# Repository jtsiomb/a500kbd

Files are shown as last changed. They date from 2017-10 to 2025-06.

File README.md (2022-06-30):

Amiga 500 PS/2 keyboard controller
==================================

About
-----
This project is a PS/2 keyboard controller for the Amiga 500. It makes it
possible to connect and use an external PS/2 keyboard with the Amiga.

It's based on an AVR atmega168 microcontroller, which reads the PS/2 keyboard
and translates scancodes to the keyboard signals expected by the Amiga.

See pictures of the PS/2 controller in my Amiga: https://imgur.com/a/rhXS8

It has been reported that this works with the A600 too, by soldering directly
on the keyboard clock and data lines. I guess it might work with the A1200 as
well, so if anyone tries it please let me know.

Directory structure:

  * `hw` - hardware: kicad files and pdf schematics.
  * `fw` - firmware for the AVR microcontroller.

Project website: http://nuclear.mutantstargoat.com/hw/amiga/a500kbd

License
-------
Copyright (C) 2017 John Tsiombikas <nuclear@member.fsf.org>

You are free to use, reproduce, modify, redistribute any parts of this project,
provided you make any derivative work you release, freely available under the
same terms.

More specifically the hardware design is released under the Creative Commons
Attribution Share-Alike license (see `LICENSE.hw` for details), and the
software/firmware is released under the GNU General Public License v3, or later
(see `LICENSE.fw` for details).

Instructions
------------
Just construct the hardware, burn the firmware, drill appropriate holes, and
connect everything together. The board is designed to sit on top of the keyboard
connector pins on the Amiga motherboard, and provides a new set of pins for the
internal keyboard to be connected on the board. Two cables need to be connected
from the board to some hole on the Amiga case: one goes to the PS/2 connector,
and the other to the DPDT switch which selects between internal and external
keyboard (see: https://i.imgur.com/ovFDP2b.jpg).

The default key mapping (can only be changed by modifying the source code at the
moment), is as follows:

  * Caps lock key is mapped to control.
  * Left control key is mapped to left amiga key.
  * Right control key is mapped to right amiga key.
  * Scroll lock is mapped to caps lock.
  * F12 is mapped to "Help".

Also the scroll lock light on the external keyboard, mirrors the drive activity
LED on the amiga.

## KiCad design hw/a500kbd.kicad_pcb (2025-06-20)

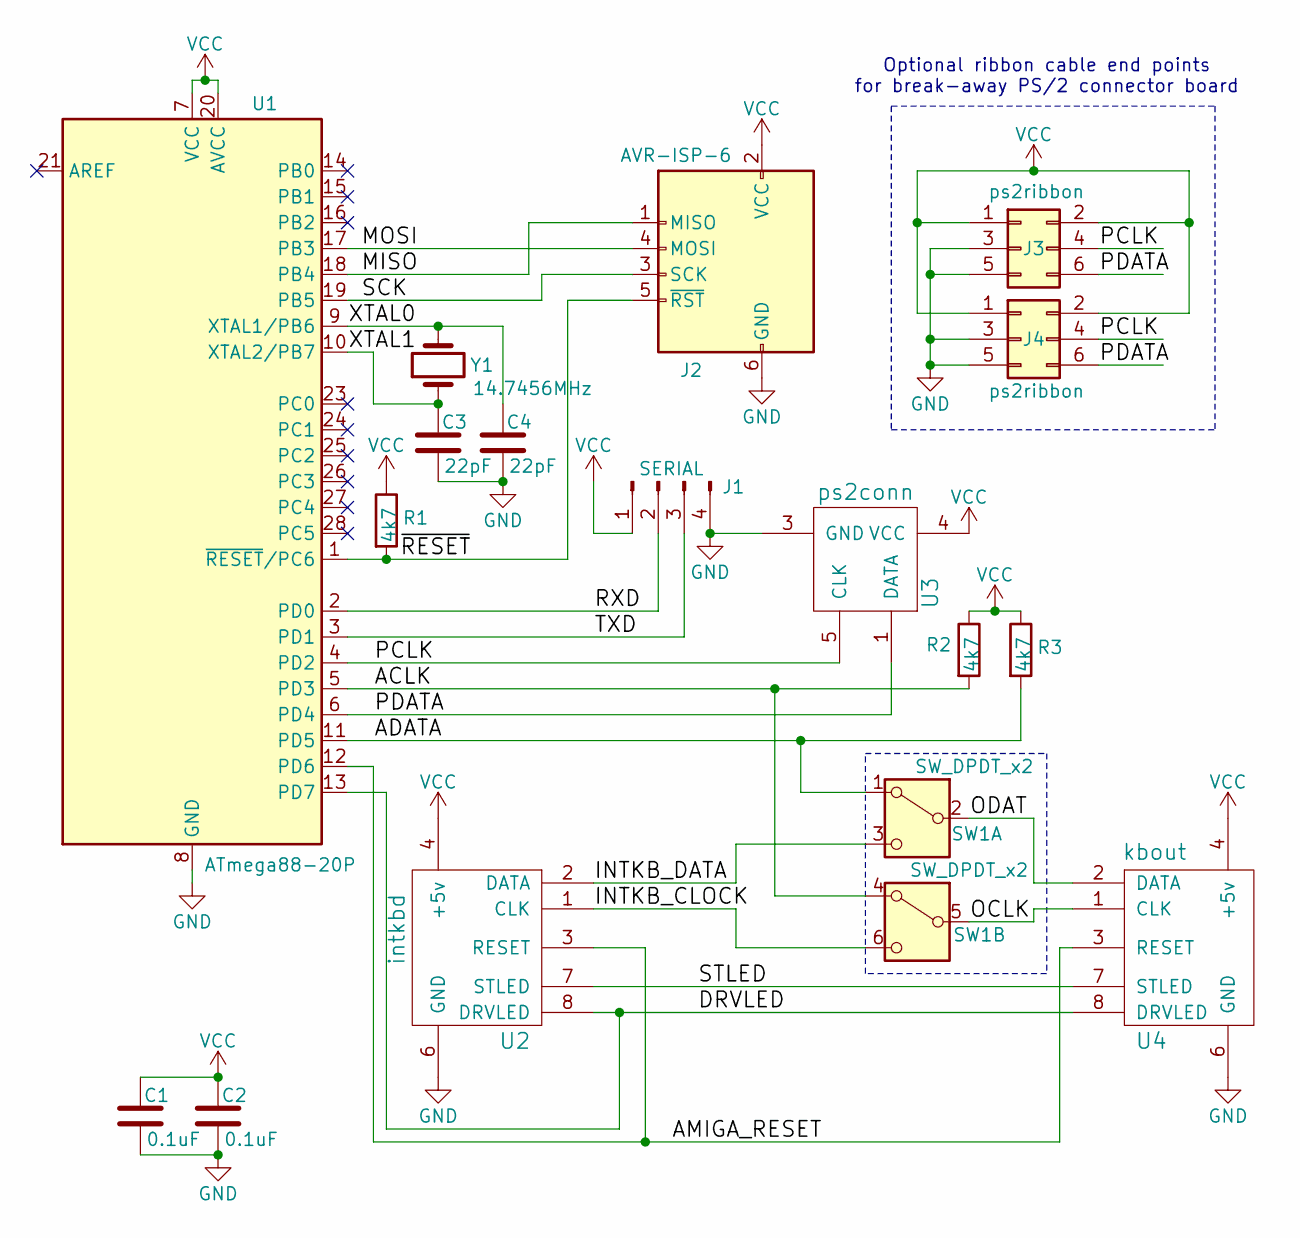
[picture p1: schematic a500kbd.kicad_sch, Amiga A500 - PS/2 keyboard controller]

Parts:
C1, C2: 0.1uF; C_Disc_D4.3mm_W1.9mm_P5.00mm
C3, C4: 22pF; C_Disc_D3.0mm_W2.0mm_P2.50mm
J1: SERIAL; PinHeader_1x04_P2.54mm_Horizontal
J2: AVR-ISP-6; IDC-Header_2x03_P2.54mm_Vertical
J3, J4: ps2ribbon; IDC-Header_2x03_P2.54mm_Vertical
R1, R2, R3: 4k7; R_Axial_DIN0207_L6.3mm_D2.5mm_P10.16mm_Horizontal
SW1: SW_DPDT_x2; kbswitch
U1: ATmega88-20P; DIP-28_W7.62mm
U2: intkbd; PinHeader_1x08_P2.54mm_Vertical
U3: ps2conn; minidin6
U4: kbout; PinSocket_1x08_P2.54mm_Vertical
Y1: 14.7456MHz; Crystal_HC49-U_Vertical

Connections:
/ACLK: R2.2, SW1.4 (A), U1.5 (PD3)
/ADATA: R3.2, SW1.1 (A), U1.11 (PD5)
/AMIGA_RESET: U1.12 (PD6), U2.3 (RESET), U4.3 (RESET)
/DRVLED: U1.13 (PD7), U2.8 (DRVLED), U4.8 (DRVLED)
/INTKB_CLOCK: SW1.6 (C), U2.1 (CLK)
/INTKB_DATA: SW1.3 (C), U2.2 (DATA)
/MISO: J2.1 (MISO), U1.18 (PB4)
/MOSI: J2.4 (MOSI), U1.17 (PB3)
/OCLK: SW1.5 (B), U4.1 (CLK)
/ODAT: SW1.2 (B), U4.2 (DATA)
/PCLK: J3.4, J4.4, U1.4 (PD2), U3.5 (CLK)
/PDATA: J3.6, J4.6, U1.6 (PD4), U3.1 (DATA)
/RXD: J1.2, U1.2 (PD0)
/SCK: J2.3 (SCK), U1.19 (PB5)
/STLED: U2.7 (STLED), U4.7 (STLED)
/TXD: J1.3, U1.3 (PD1)
/XTAL0: C4.1, U1.9 (XTAL1/PB6), Y1.2
/XTAL1: C3.1, U1.10 (XTAL2/PB7), Y1.1
/~RESET: J2.5 (~RST), R1.2, U1.1 (~RESET/PC6)
GND: C1.2, C2.2, C3.2, C4.2, J1.4, J2.6 (GND), J3.3, J3.5, J4.3, J4.5, U1.8 (GND), U1.22 (GND), U2.6 (GND), U3.3 (GND), U4.6 (GND)
VCC: C1.1, C2.1, J1.1, J2.2 (VCC), J3.1, J3.2, J4.1, J4.2, R1.1, R2.1, R3.1, U1.7 (VCC), U1.20 (AVCC), U2.4 (+5v), U3.4 (VCC), U4.4 (+5v)

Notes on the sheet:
Optional ribbon cable end points for break-away PS/2 connector board

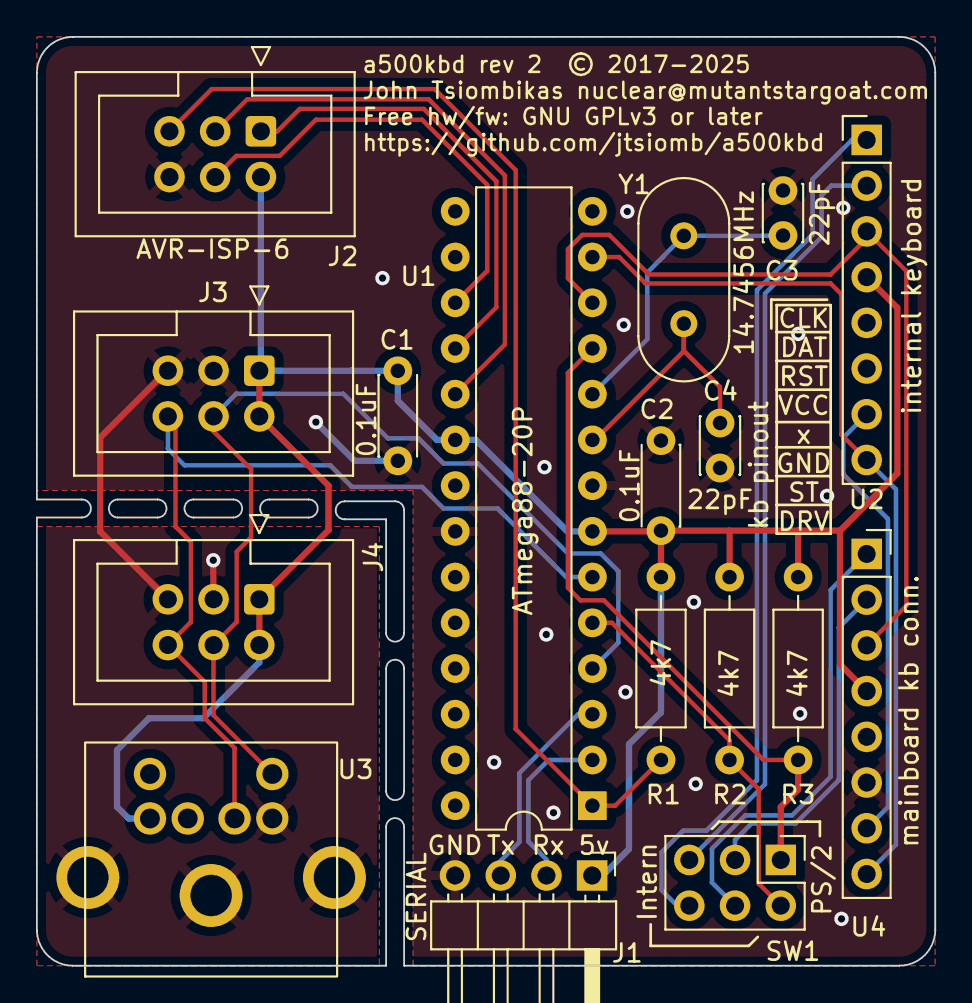
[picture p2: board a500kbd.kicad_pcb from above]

Board: 2 copper layers, 49.9 x 51.6 mm, 17 parts (0 on the bottom side), 21 nets.

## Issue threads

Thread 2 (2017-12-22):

Tested on an Amiga 600!

Quantum-cross, 2017-12-22:
Just wanted to let you know that I've tested this code on an Amiga 600. I soldered directly to the KB_CLOCK and KB_DATA lines.

You can go ahead and add that into the readme or whatever.

Thank you so much for developing this!!!

Now I have a numpad on the A600 :)

jtsiomb, 2017-12-22:
Excellent! Glad to hear it, thanks for letting me know. I've added the info to the readme file, and I'm closing this as it's not really an "issue". An email would be preferable :)

Quantum-cross, 2017-12-22:
Sorry, I didn't see the email in the readme, whoops!

Closed 2017-12-22.

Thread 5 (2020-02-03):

(Question) Why 14.7456 mhz? (Will 16MHz likely work as well?)

wyatt8740, 2020-02-03:
Sorry, this isn't really an issue as much as a question from someone dumb (me).
Is there any reason why 14.7456 MHz was chosen for this project? Was it just "I happened to have that crystal handy" or is it a good match for the speed of the keyboard bus?

I ask this because I'm wondering if there is there anything you can think of that would make this work worse at 16mhz, which would let me just program an Arduino (ATMega328P) with a 16 MHz crystal that I've got lying around with an ISP and not have to scavenge for any parts. I'm not very knowledgeable about the Amigas, having only gotten my first a couple years ago and only gotten to work on it in the last few months. I'll enjoy being able to use it with my Model M.

jtsiomb, 2020-02-03:
Please in the future send questions through email. This is for bug reports.

The reason for the specific crystal value, is that it divides nicely into standard UART rates like the 9600 baud I'm using for the debug serial port. Using frequencies like 16MHz would introduce transmission errors in this case. There's a nice table in the AVR atmega datasheet which shows the error rate for various different frequencies.

For the arduino I assume this isn't an issue, since you can use the USB serial port for this, but I never actually used an arduino so I'm not sure. In any case, this is just for debugging purposes, and it shouldn't affect the operation of the controller in any way.

wyatt8740, 2020-02-03:
My bad. Thanks for the quick reply. Some people hate getting email so I'm never sure.

That makes sense; on the Uno there's a separate AVR as a 'serial-to-USB-packets' chip (like an FTDI chip). I probably could get away with 16mhz, then. Sorry again about using the wrong channel of communication. Thanks.

Closed 2020-02-03.

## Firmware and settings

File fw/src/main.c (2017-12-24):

#include <stdio.h>
#include <ctype.h>
#include <avr/io.h>
#include <avr/interrupt.h>
#include <util/delay.h>
#include "serial.h"
#include "scantbl.h"
#include "ps2kbd.h"
#include "amigakb.h"
#include "defs.h"
#include "timer.h"

enum {
	KF_BRK = 1,
	KF_EXT = 2,
	KF_EXT1 = 4,

	KF_CTRL		= 16,
	KF_LAMIGA	= 32,
	KF_RAMIGA	= 64
};
#define KF_TRANSIENT	0x0f
#define KF_STICKY		0xf0

#define RESET_WAIT 1000

static unsigned char led_state;

int main(void)
{
	unsigned int keyflags = 0;
	unsigned char c, keycode, prev_drvled = 0;
	int press;

	/* disable all pullups globally */
	MCUCR |= 1 << PUD;

	DDRD = 0;
	PORTD = 0;
	EIMSK = 0;	/* mask external interrupts */
	EICRA = (1 << ISC11) | (1 << ISC01);	/* falling edge interrupts */

	init_timer();

	/* initialize the UART and enable interrupts */
	init_serial(9600);
	sei();

	printf("PS/2 keyboard controller - John Tsiombikas <nuclear@member.fsf.org>\r\n");

	EIMSK = (1 << INT0) | (1 << INT1);	/* enable ps/2 clock interrupt */

	ps2setled(0);	/* start with all LEDs off */

	for(;;) {
		while(!ps2pending()) {
			unsigned char drvled = PIND & ADRVLED_BIT;
			if(drvled != prev_drvled) {
				prev_drvled = drvled;
				if(drvled) {
					led_state |= PS2LED_SCRLK;
				} else {
					led_state &= ~PS2LED_SCRLK;
				}
				ps2setled(led_state);
			}
		}

		c = ps2read();
		switch(c) {
		case 0xe0:	/* extended */
			keyflags |= KF_EXT;
			break;

		case 0xe1:	/* extended */
			keyflags |= KF_EXT1;
			break;

		case 0xf0:	/* break code */
			keyflags |= KF_BRK;
			break;

		default:
			press = !(keyflags & KF_BRK);

			keycode = 0xff;
			if(keyflags & KF_EXT) {
				if(c < KEYMAP_EXT_SIZE) {
					keycode = keymap_ext[(int)c];
				}
			} else if(keyflags & KF_EXT1) {
			} else {
				if(c < KEYMAP_NORMAL_SIZE) {
					keycode = keymap_normal[(int)c];
				}
			}

			switch(keycode) {
			case AMIKEY_CTRL:
				if(press)
					keyflags |= KF_CTRL;
				else
					keyflags &= ~KF_CTRL;
				break;

			case AMIKEY_LAMI:
				if(press)
					keyflags |= KF_LAMIGA;
				else
					keyflags &= ~KF_LAMIGA;
				break;

			case AMIKEY_RAMI:
				if(press)
					keyflags |= KF_RAMIGA;
				else
					keyflags &= ~KF_RAMIGA;
				break;

			default:
				break;
			}

			if((keyflags & (KF_CTRL | KF_RAMIGA | KF_LAMIGA)) == (KF_CTRL | KF_RAMIGA | KF_LAMIGA)) {
				printf("CTRL - AMIGA - AMIGA!\r\n");
				amikb_reset();

				keyflags = 0;

				reset_timer();
				while(get_msec() < RESET_WAIT);
				ps2clearbuf();

				break;
			}

			if(keycode != 0xff) {
				int press = ~keyflags & KF_BRK;
				amikb_sendkey(keycode, press);
				if(keycode == 0x62 && press) {
					led_state ^= PS2LED_CAPSLK;
					ps2setled(led_state);
				}
				/*printf("scancode %x -> [%s] amiga key %xh\r\n", (unsigned int)c, press ? "press" : "release", keycode);*/
			} else {
				printf("PS/2 unknown command or keycode: %x\r\n", (unsigned int)c);
			}
			keyflags &= ~KF_TRANSIENT;
		}
	}
	return 0;
}

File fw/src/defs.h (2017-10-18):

#ifndef DEFS_H_
#define DEFS_H_

#include <avr/io.h>

/* pin assignments:
 * D2	PS/2 clock (INT0)
 * D3	amikbd clock (INT1)
 * D4	PS/2 data
 * D5	amikbd data
 * D6	amiga reset
 * D7	amiga drvled in
 */

#define PCLK	2
#define ACLK	3
#define PDATA	4
#define ADATA	5
#define ARST	6
#define ADRVLED	7

#define PCLK_BIT	(1 << PCLK)
#define ACLK_BIT	(1 << ACLK)
#define PDATA_BIT	(1 << PDATA)
#define ADATA_BIT	(1 << ADATA)
#define ARST_BIT	(1 << ARST)
#define ADRVLED_BIT	(1 << ADRVLED)

#endif	/* DEFS_H_ */

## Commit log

2017-10-18 amiga 500 ps/2 keyboard controller initial commit
    [a500kbd.sch]
2017-12-23 Trying to solve the spurious keystrokes after reset problem.
    [amigakb.c, main.c]
2017-12-24 Fix spurious keystrokes on reset. Increase ps2 buffer to 32 for multiple keypresses
    [main.c, ps2kbd.c]
2017-12-24 minor coding style fixes
    [main.c, ps2kbd.c]
2022-06-30 kicad project update
    [a500kbd.sch]
2025-05-21 build for atmega88, and attempt to improve reset reliability
    [amigakb.c]
2025-05-21 PCB design
    [a500kbd.kicad_pcb, a500kbd.kicad_sch, a500kbd.sch]
2025-05-22 fix pcb cutouts and minor re-routing of a signal
    [a500kbd.kicad_pcb, a500kbd.kicad_sch]
2025-05-23 fixed (swapped) the placement of the amiga keyboard connectors
    [a500kbd.kicad_pcb]
2025-05-24 fixed mirrored ps2 connector in schematic
    [a500kbd.kicad_pcb, a500kbd.kicad_sch]
2025-06-20 fixed pcb, ps/2 connector facing the wrong way
    [a500kbd.kicad_pcb, a500kbd.kicad_sch]

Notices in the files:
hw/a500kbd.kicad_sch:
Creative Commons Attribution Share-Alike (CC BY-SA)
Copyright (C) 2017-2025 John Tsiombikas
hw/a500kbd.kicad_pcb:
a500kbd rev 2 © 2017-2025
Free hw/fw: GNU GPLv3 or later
